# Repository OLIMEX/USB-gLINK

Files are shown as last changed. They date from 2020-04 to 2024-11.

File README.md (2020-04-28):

# USB-gLINK

Industrial grade USB LTE cat 4 module optimized for IoT applications with integrated LiPo Battery power supply charger and Navigation.

Product page: https://www.olimex.com/Products/IoT/LTE/USB-gLINK/open-source-hardware

* Works with OLinuXino OSHW Linux Computers, Beaglebone and Raspberry Pi.

* LTE speed 150Mbps downlink and 50Mbps uplink. Backward-compatible with existing EDGE and GSM/GPRS networks.

* Navigation Supports: GPS, GLONASS, BeiDou/Compass, Galileo and QZSS navigation.

* Protocols: TCP / UDP / PPP / FTP / HTTP / NTP / PING / QMI / NITZ / SMTP / MQTT / CMUX / HTTPS / FTPS / SMTPS / SSL / MMS / FILE.

* USB serial drivers for Windows 7/8/8.1/10, Linux and Android.

* Works anywehere in the world: B1 / B2 / B3 / B4 / B5 / B7 / B8 / B12 / B13 / B18 / B19 / B20 / B25 / B26 / B28 / B38 / B39 / B40 / B41.

* Approvals Carrier: Deutsche Telekom (Europe), Verizon/AT&T/Sprint/U.S. Cellular/T-Mobile (North America), Telus/Rogers (Canada)

* Regulatory: GCF (Global), CE (Europe), FCC/PTCRB (North America), IC (Canada), Anatel (Brazil), IFETEL (Mexico), SRRC/CCC/NAL (China), KC (South Korea), NCC (Taiwan, China), JATE/TELEC (Japan), RCM (Australia & New Zealand), FAC (Russia), NBTC (Thailand), IMDA (Singapore), ICASA (South Africa)

## Licensee
* Hardware is released under CERN Open Hardware Licence Version 2 -
Strongly Reciprocal
* Software is released under GPL3 Licensee
* Documentation is released under CC BY-SA 3.0

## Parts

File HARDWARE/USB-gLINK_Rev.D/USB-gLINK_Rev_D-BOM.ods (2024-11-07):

Qty | Designation | Package | Designator
1 | 0R/R0402 | R_0402_5MIL_DWS | R19
1 | 10R/R0402 | R_0402_5MIL_DWS | R20
5 | 22R/R0402 | R_0402_5MIL_DWS | R13,R14,R16,R17,R18
1 | 100R/R0402 | R_0402_5MIL_DWS | R29
5 | 2.2k/R0402 | R_0402_5MIL_DWS | R6,R7,R8,R9,R10
1 | 4.7k/R0402 | R_0402_5MIL_DWS | R11
1 | 33k/1%/R0603 | R_0603_5MIL_DWS | R3
5 | 10k/R0402 | R_0402_5MIL_DWS | R2,R4,R5,R12,R28
1 | 200k/1%/R0603 | R_0603_5MIL_DWS | R1
1 | 470k/R0402 | R_0402_5MIL_DWS | R30
1 | 1M/R0402 | R_0402_5MIL_DWS | R15
2 | 10pF/50V/5%/COG/C0402 | C_0402_5MIL_DWS | C16,C21
6 | 33pF/50V/5%/COG/C0402 | C_0402_5MIL_DWS | C3,C8,C9,C11,C15,C20
1 | 100pF/50V/5%/COG/C0402 | C_0402_5MIL_DWS | C33
4 | 10nF/10V/10%/X5R/C0402 | C_0402_5MIL_DWS | C10,C30,C31,C32
7 | 100nF/10V/10%/X5R/C0402 | C_0402_5MIL_DWS | C1,C7,C14,C19,C28,C29,C34
5 | 22uF/6.3V/20%/X5R/C0603 | C_0603_5MIL_DWS | C2,C4,C5,C6,C35
4 | 47uF/6.3V/20%/X5R/C0805 | C_0805_5MIL_DWS | C12,C13,C17,C18
1 | 33nH/0402 | L_0402_5MIL_DWS | L2
1 | 2.5uH/3.2A/26mR/20%/10.3x10.4x 3.0mm(HSMRH103R-2R5M) | HSMRH103R | L1
2 | 1N5822/SMA | SMA-KA | D1,D2
1 | 1N5819S4/SOD123 | SOD-123_1C-2A_KA | D3
1 | LED/Green/0603 | LED_0603_KA | ModStat1
2 | LED/Yellow/0603 | LED_0603_KA | CHRG1,NetStat1
1 | LED/Red/0603 | LED_0603_KA | NetMode1
2 | BSS138(SOT23-3) | SOT23 | FET2,FET5
3 | IRLML6402(SOT23-3) | SOT23 | FET1,FET3,FET4
2 | LMUN2211LT1G(SOT23-3) | SOT23 | T2,T3
1 | Quectel_EG25-G_Module | Quectel_EG25-G_Module_LGA- 144_32.0mmx29.0mmx2.4mm | U3
1 | SY8113(SOT23-6) | SOT23-6 | U1
1 | BL4054B-42TPRN(SOT23-5) | SOT-23-5 | U2
1 | SIMNANO-6P-1.3H | SIMNANO-6P-1.3H | SIM1
1 | MISB-SWMM-5B-LF(USB_MICRO) | USB-MICRO_MISB-SWMM-5B_LF | USB-DEV1
1 | DW02S | LIPO_BAT_VERTICAL_DW02S | BAT1
1 | (U.FL-R-SMT-1)+(ANTENNA- GPS-25x25-200-u.FL) | U.FL-R-SMT-1 | ANT_GNSS1
1 | (U.FL-R-SMT-1)+(ANTENNA_ GSM_U.FL(PCB)) | U.FL-R-SMT-1 | ANT_MAIN1
2 | IT1185AU2 | IT1185AU2_V2 | PWR_KEY1,RST_KEY1
1 | Opened | SJ_1_SMALLER | BOOT_E1
1 | Soldered | SJ_1_SMALLER | Start_E1
2 | NA(YA-V36P-2X20-LF) | GPCB127SMT-02X20(YA-V36P-2X20-LF) | EXT2,EXT1
6 | NA/C0402 | C_0402_5MIL_DWS | C22,C23,C24,C25,C26,C27
1 | NA(U.FL-R-SMT-1) | U.FL-R-SMT-1 | ANT_DIV1
1 | NA(0R/R0402) | R_0402_5MIL_DWS | R21
1 | NA(1.5k/R0402) | R_0402_5MIL_DWS | R22
4 | NA(10k/R0402) | R_0402_5MIL_DWS | R23,R24,R25,R32
2 | NA(3.9k/R0402) | R_0402_5MIL_DWS | R26,R27
2 | NA(100nF/10V/10%/X5R/C0402) | C_0402_5MIL_DWS | C36,C37
1 | NA(4.7k/R0402) | R_0402_5MIL_DWS | R31
1 | NA(1M/R0402) | R_0402_5MIL_DWS | R33
1 | NA(470k/R0402) | R_0402_5MIL_DWS | R34

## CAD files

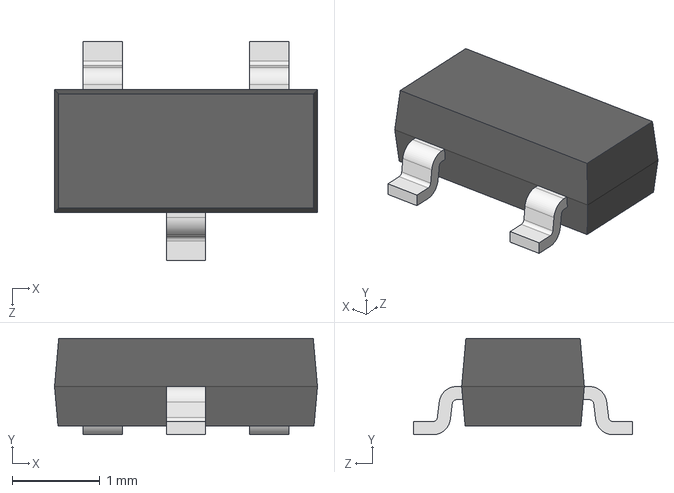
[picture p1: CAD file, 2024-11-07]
HARDWARE/USB-gLINK_Rev.D/3d/SOT-23.step
3.00 x 1.10 x 2.50 mm

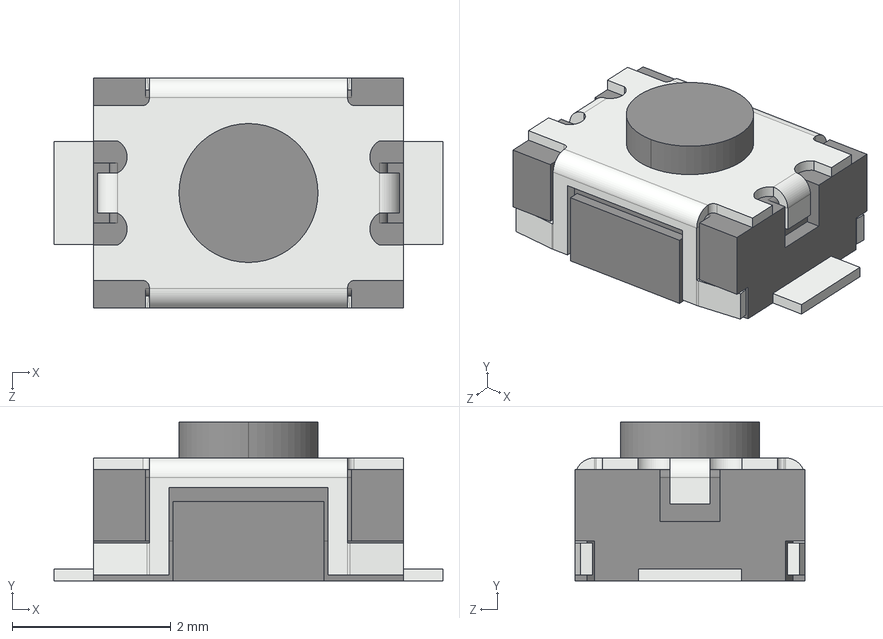
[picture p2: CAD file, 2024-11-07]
HARDWARE/USB-gLINK_Rev.D/3d/it1185.step
4.90 x 2.00 x 2.90 mm

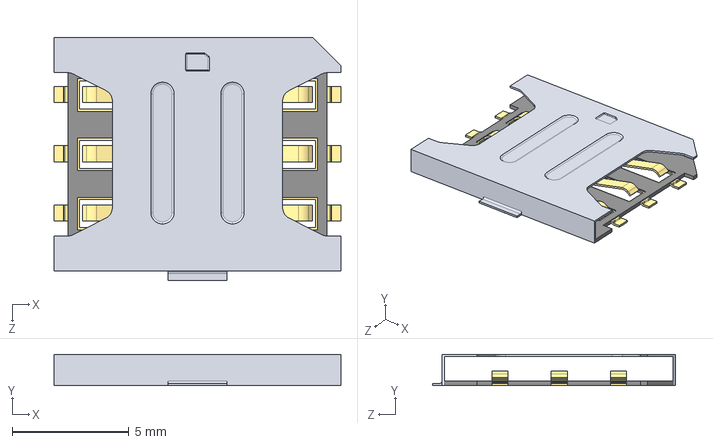
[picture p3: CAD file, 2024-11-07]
HARDWARE/USB-gLINK_Rev.D/3d/User Library-nano sim.STEP
12.3 x 1.35 x 10.4 mm

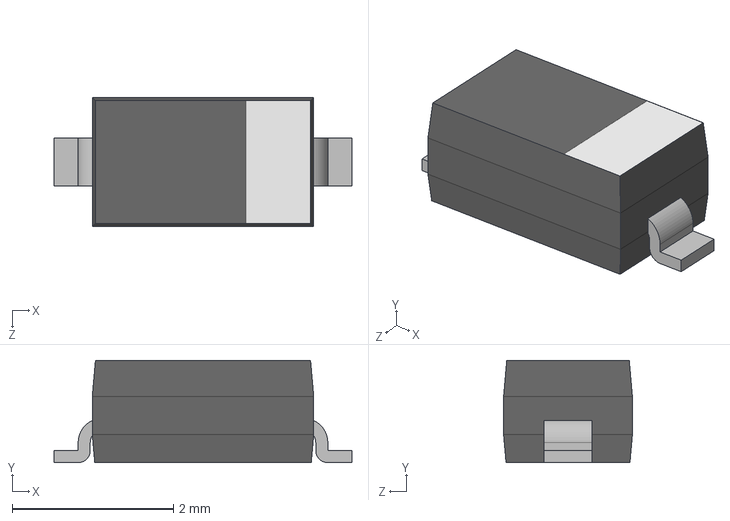
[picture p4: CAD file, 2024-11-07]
HARDWARE/USB-gLINK_Rev.D/3d/SOD123.step
3.70 x 1.27 x 1.60 mm

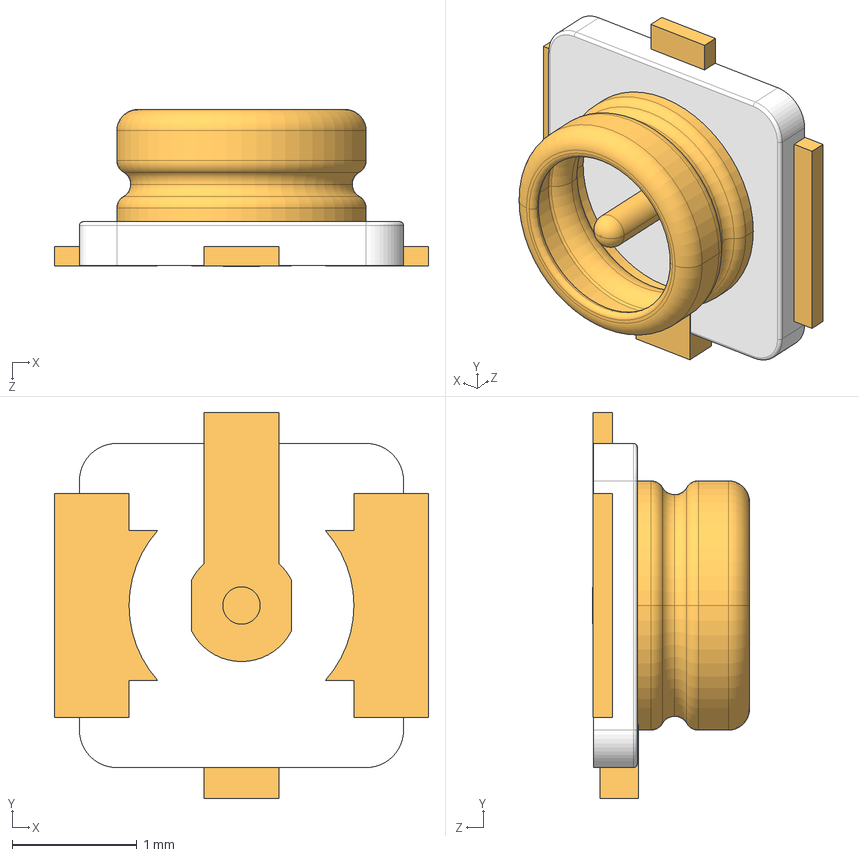
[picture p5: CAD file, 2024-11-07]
HARDWARE/USB-gLINK_Rev.D/3d/U_FL-R-SMT-1.step
3.00 x 3.10 x 1.26 mm

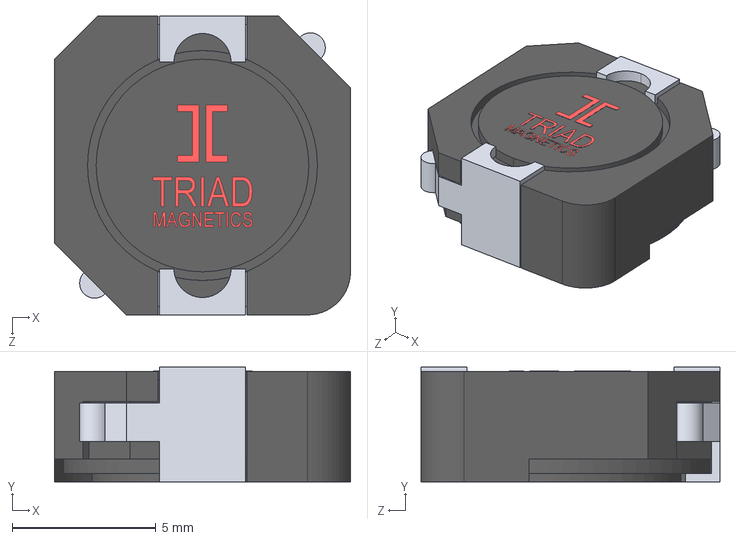
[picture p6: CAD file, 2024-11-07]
HARDWARE/USB-gLINK_Rev.D/3d/L_HSMRH103R_Triad_Magnetics-AX104R-150.STEP
10.3 x 4.00 x 10.4 mm

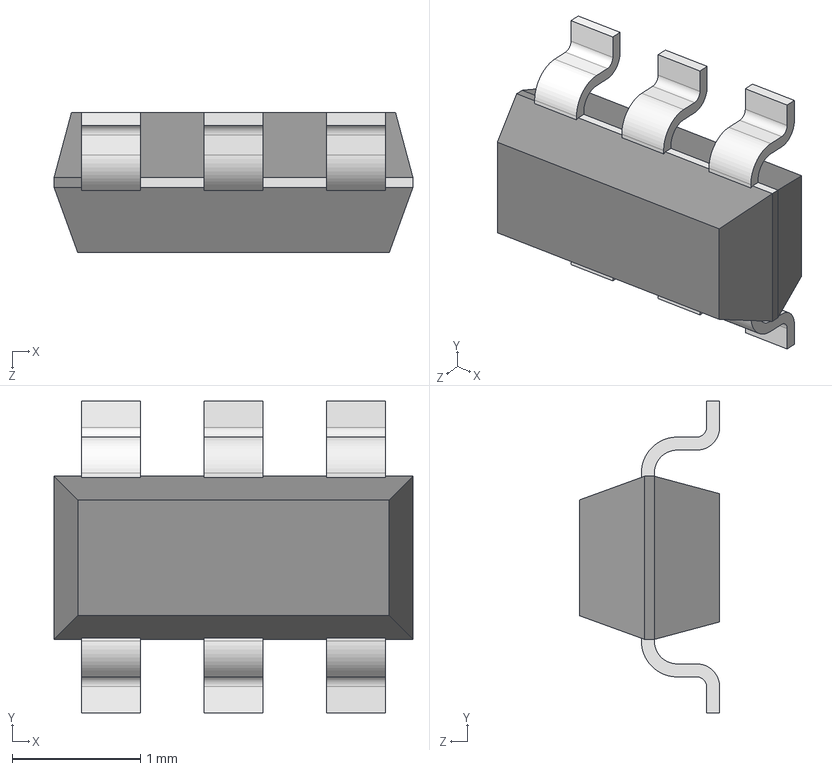
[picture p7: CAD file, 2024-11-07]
HARDWARE/USB-gLINK_Rev.D/3d/SOT-23-6.step
2.79 x 2.43 x 1.09 mm

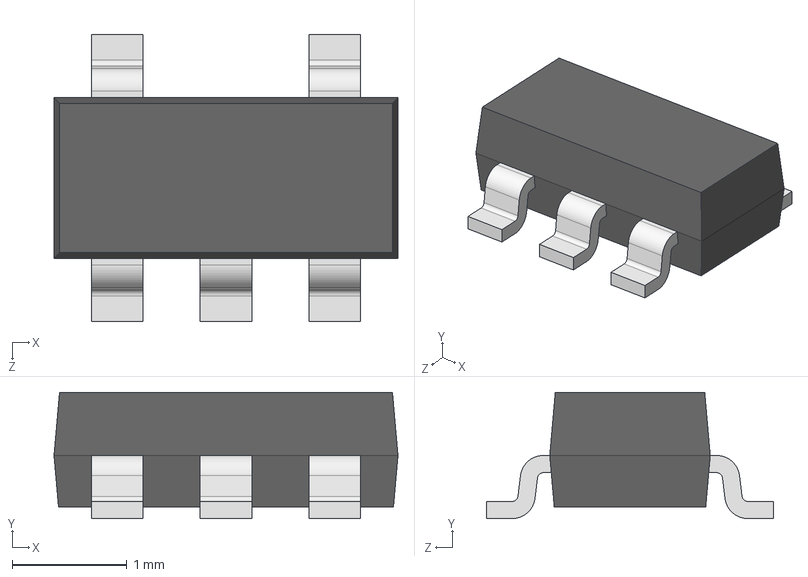
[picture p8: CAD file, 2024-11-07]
HARDWARE/USB-gLINK_Rev.D/3d/SOT-23-5.step
3.00 x 1.10 x 2.50 mm

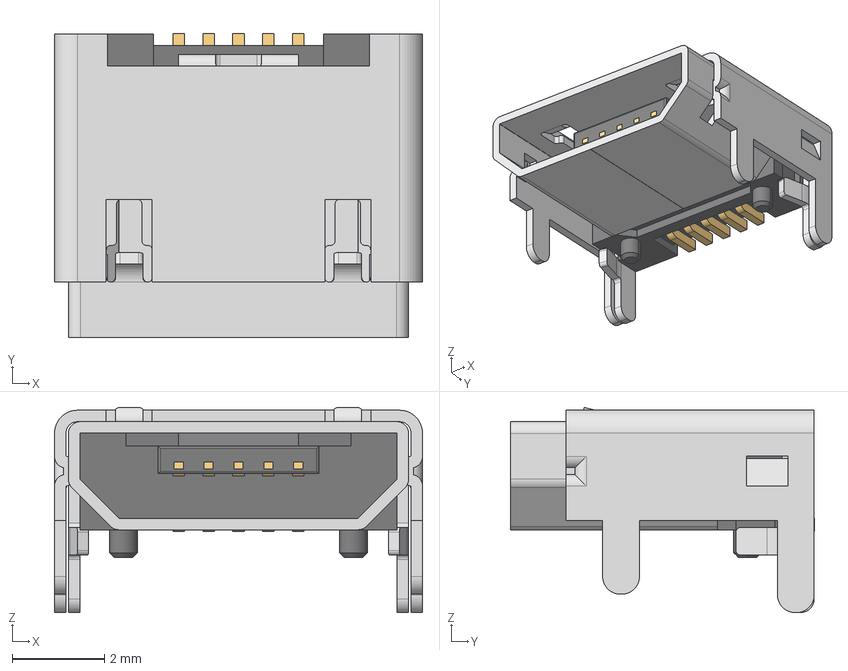
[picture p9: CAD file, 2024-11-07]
HARDWARE/USB-gLINK_Rev.D/3d/usb_micro_4p.stp
8.00 x 6.60 x 4.46 mm

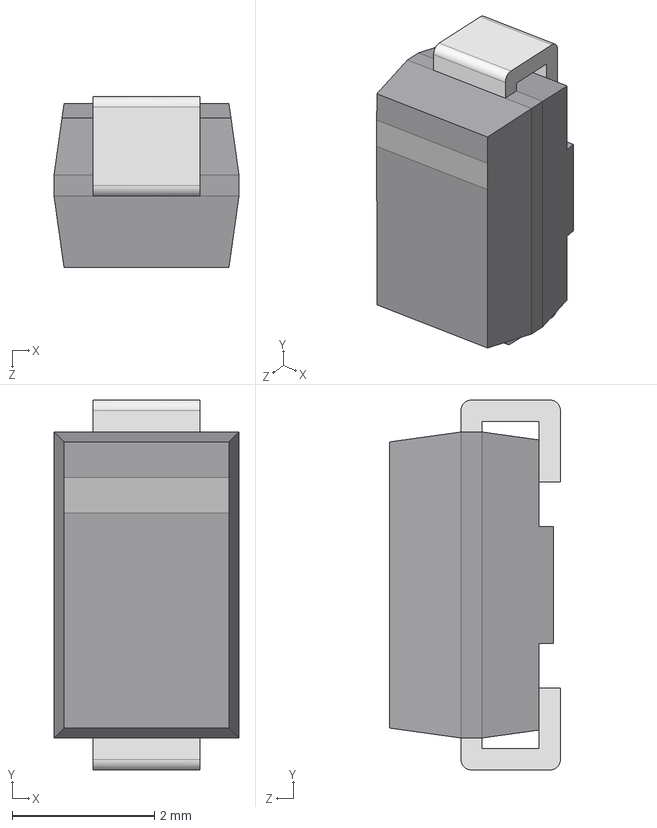
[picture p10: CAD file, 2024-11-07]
HARDWARE/USB-gLINK_Rev.D/3d/DO-214AC_SMA.step
2.60 x 5.20 x 2.40 mm

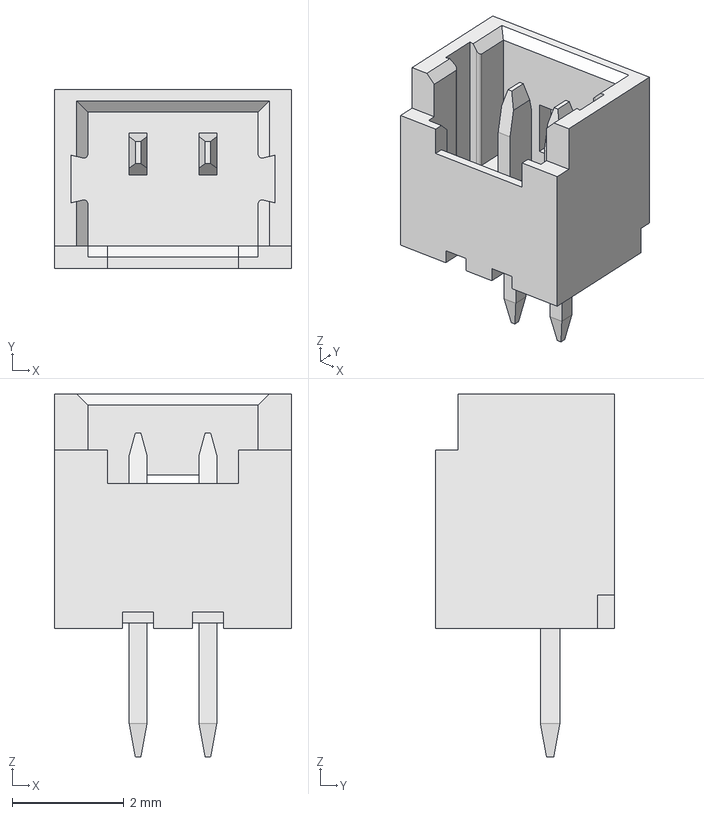
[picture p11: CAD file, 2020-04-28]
HARDWARE/USB-gLINK_Rev.D/3d/Molex_PicoBlade_530470210.step
4.25 x 3.20 x 6.50 mm

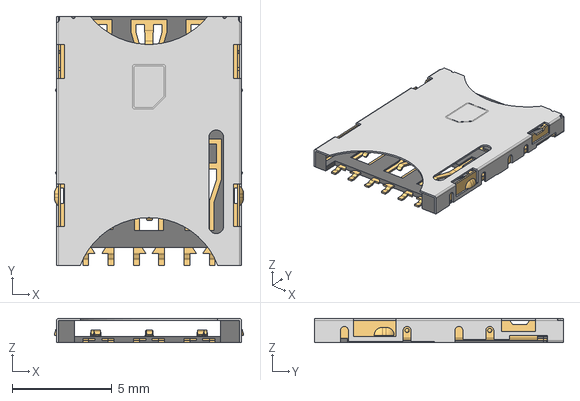
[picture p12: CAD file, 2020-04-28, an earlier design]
HARDWARE/USB-gLINK_Rev.C/3d/NANO-SIM_Wurth_Electronics_693043020611.step
9.50 x 12.5 x 1.21 mm
693043020611_SHIELDING

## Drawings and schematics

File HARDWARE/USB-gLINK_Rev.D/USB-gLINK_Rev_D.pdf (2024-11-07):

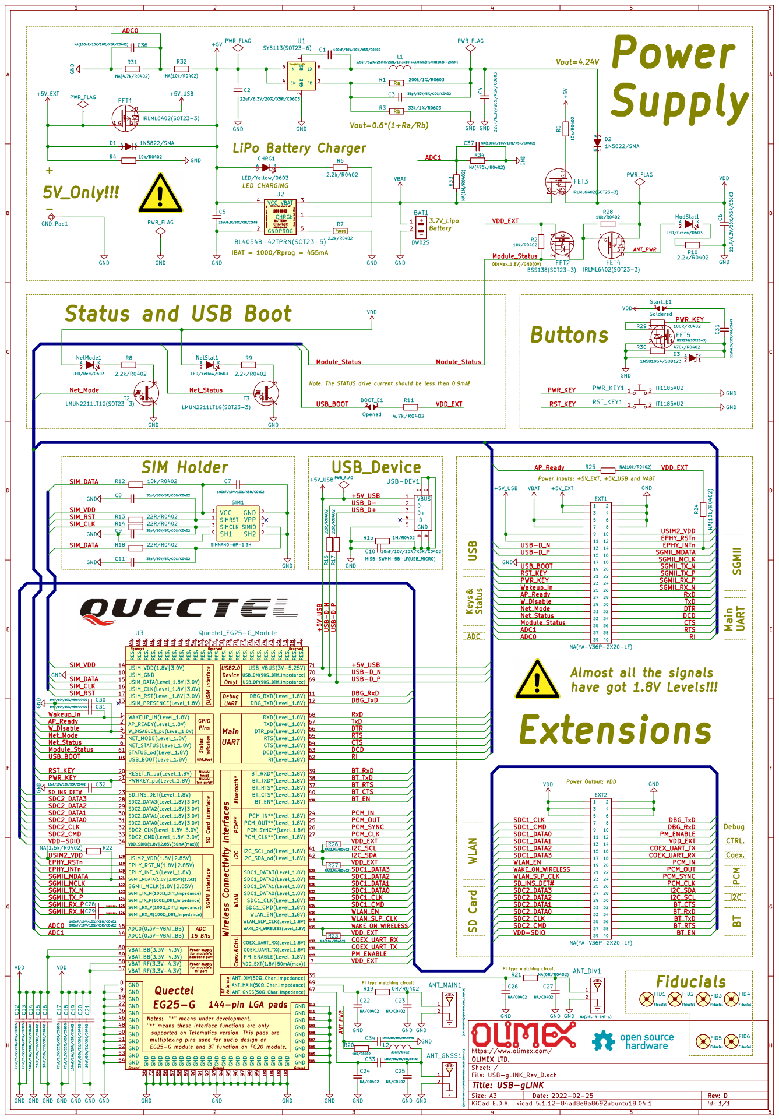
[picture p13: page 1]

3.7V_Lipo Battery Note: The STATUS drive current should be less than 0.9mA!

Power Output: VDD Status and USB Boot

PI type matching circuit SIM Holder

Power Inputs: +5V_EXT, +5V_USB and VABT Almost all the signals
VBAT

PWR_KEY RI DCD
Module Module multiplexing pins used for audio design on Notes:

File: USB-gLINK_Rev_D.sch Sheet: / OLIMEX LTD. https://www.olimex.com/ "*" means under development. "**"means these interface functions are only (U)SIM Interface

for module's GPIO
RF part SD Card Interface SGMII Interface Status

2 ANT_GNSS1 (U.FL-R-SMT-1)+(ANTENNA-GPS-25x25-200-u.FL) 1

Power supply Power supply Quectel

supported on Telematics version. This pads are

EG25-G module and BT function on FC20 module.

Id: 1/1 Title: USB-gLINK

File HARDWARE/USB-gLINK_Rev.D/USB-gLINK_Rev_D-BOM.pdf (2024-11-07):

USB-gLINK_Rev_D_BOM | 02/28/2022

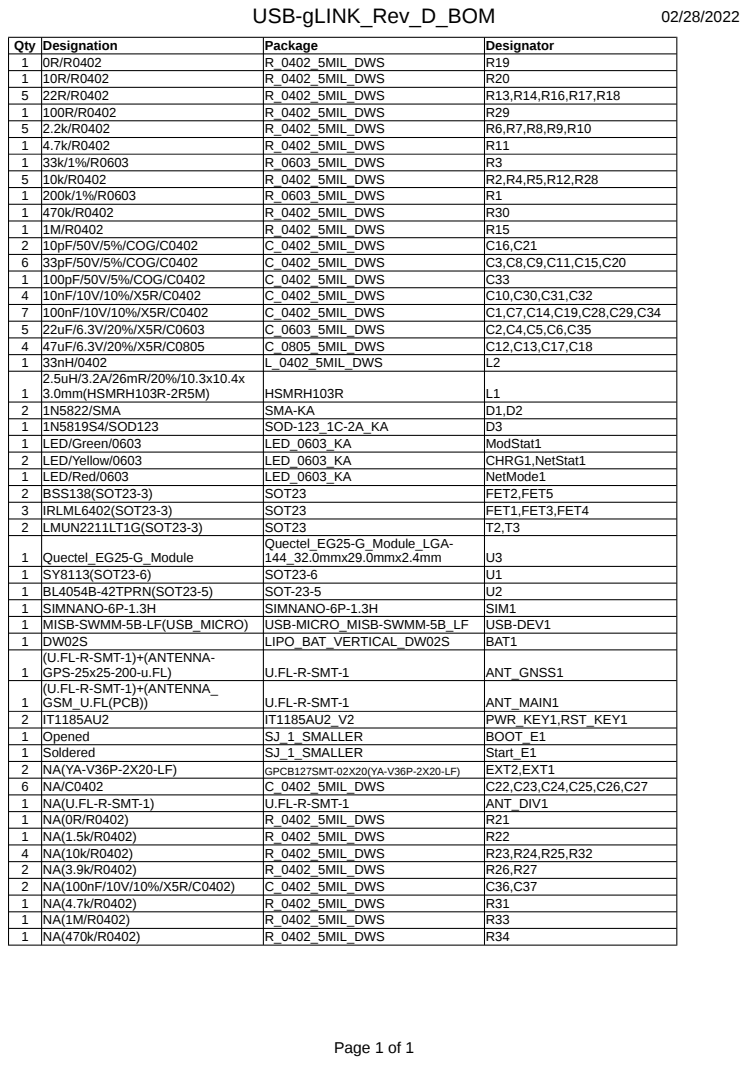
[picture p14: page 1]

1 MISB-SWMM-5B-LF(USB_MICRO) USB-MICRO_MISB-SWMM-5B_LF USB-DEV1
(U.FL-R-SMT-1)+(ANTENNA-
GPS-25x25-200-u.FL)
(U.FL-R-SMT-1)+(ANTENNA_
GSM_U.FL(PCB))

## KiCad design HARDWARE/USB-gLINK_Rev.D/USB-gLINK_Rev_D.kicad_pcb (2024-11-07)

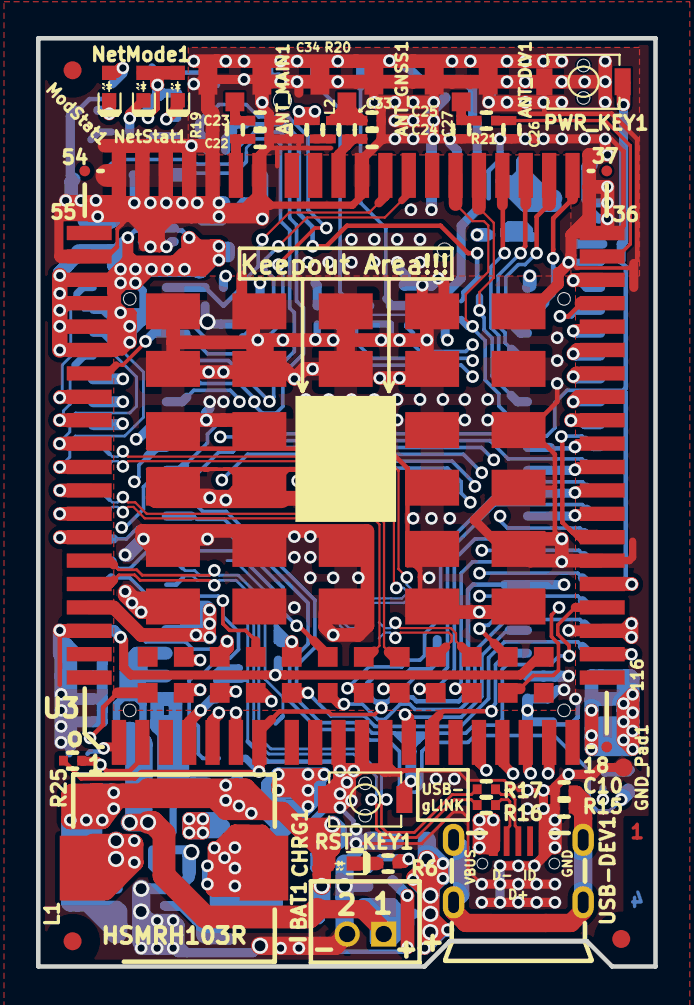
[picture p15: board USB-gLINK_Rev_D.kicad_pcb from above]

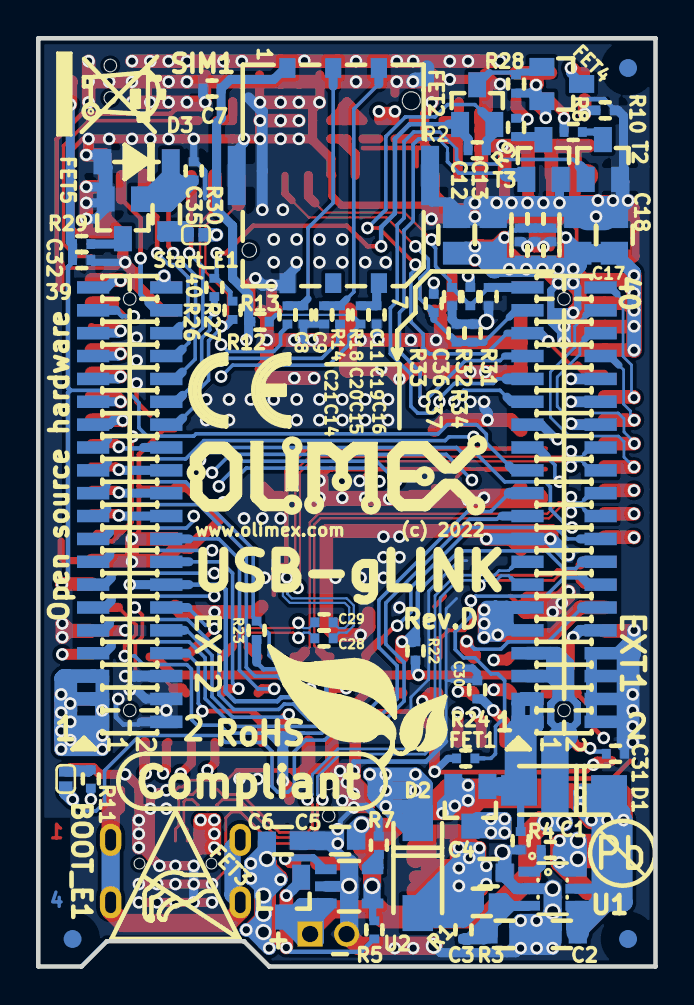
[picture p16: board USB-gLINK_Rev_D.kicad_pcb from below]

Board: 4 copper layers, 34.3 x 51.6 mm, 115 parts (80 on the bottom side), 107 nets.

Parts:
ANT_DIV1: NA(U.FL-R-SMT-1); U.FL-R-SMT-1
ANT_GNSS1: (U.FL-R-SMT-1)+(ANTENNA-GPS-25x25-200-u.FL); U.FL-R-SMT-1
ANT_MAIN1: (U.FL-R-SMT-1)+(ANTENNA_GSM_U.FL(PCB)); U.FL-R-SMT-1
BAT1: DW02S; LIPO_BAT_VERTICAL_DW02S
BOOT_E1: Opened; SJ_1_SMALLER
C1, C7, C14, C19, C28, C29, C34: 100nF/10V/10%/X5R/C0402; C_0402_5MIL_DWS
C2, C4, C5, C6, C35: 22uF/6.3V/20%/X5R/C0603; C_0603_5MIL_DWS
C3, C8, C9, C11, C15, C20: 33pF/50V/5%/COG/C0402; C_0402_5MIL_DWS
C10, C30, C31, C32: 10nF/10V/10%/X5R/C0402; C_0402_5MIL_DWS
C12, C13, C17, C18: 47uF/6.3V/20%/X5R/C0805; C_0805_5MIL_DWS
C16, C21: 10pF/50V/5%/COG/C0402; C_0402_5MIL_DWS
C22, C23, C24, C25, C26, C27: NA/C0402; C_0402_5MIL_DWS
C33: 100pF/50V/5%/COG/C0402; C_0402_5MIL_DWS
C36, C37: NA(100nF/10V/10%/X5R/C0402); C_0402_5MIL_DWS
CE_Logo: CE_Sign
CHRG1: LED/Yellow/0603; LED_0603_KA
D1, D2: 1N5822/SMA; SMA-KA
D3: 1N5819S4/SOD123; SOD-123_1C-2A_KA
EXT1, EXT2: NA(YA-V36P-2X20-LF); GPCB127SMT-02X20(YA-V36P-2X20-LF)
FET1, FET3, FET4: IRLML6402(SOT23-3); SOT23
FET2, FET5: BSS138(SOT23-3); SOT23
FID1, FID2, FID3, FID4, FID5, FID6: Fiducial; Fiducial1x3
GND_Pad1: TESTPAD; TESTPAD_40-ROUND
L1: 2.5uH/3.2A/26mR/20%/10.3x10.4x3.0mm(HSMRH103R-2R5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; HSMRH103R
L2: 33nH/0402; L_0402_5MIL_DWS
Logo_OLimeX: OLIMEX_LOGO_TB
Logo_RecycleBin: LOGO_RECYCLEBIN_1
ModStat1: LED/Green/0603; LED_0603_KA
NetMode1: LED/Red/0603; LED_0603_KA
NetStat1: LED/Yellow/0603; LED_0603_KA
PWR_KEY1: IT1185AU2; IT1185AU2_V2
R1: 200k/1%/R0603; R_0603_5MIL_DWS
R2, R4, R5, R12, R28: 10k/R0402; R_0402_5MIL_DWS
R3: 33k/1%/R0603; R_0603_5MIL_DWS
R6, R7, R8, R9, R10: 2.2k/R0402; R_0402_5MIL_DWS
R11: 4.7k/R0402; R_0402_5MIL_DWS
R13, R14, R16, R17, R18: 22R/R0402; R_0402_5MIL_DWS
R15: 1M/R0402; R_0402_5MIL_DWS
R19: 0R/R0402; R_0402_5MIL_DWS
R20: 10R/R0402; R_0402_5MIL_DWS
R21: NA(0R/R0402); R_0402_5MIL_DWS
R22: NA(1.5k/R0402); R_0402_5MIL_DWS
R23, R24, R25, R32: NA(10k/R0402); R_0402_5MIL_DWS
R26, R27: NA(3.9k/R0402); R_0402_5MIL_DWS
R29: 100R/R0402; R_0402_5MIL_DWS
R30: 470k/R0402; R_0402_5MIL_DWS
R31: NA(4.7k/R0402); R_0402_5MIL_DWS
R33: NA(1M/R0402); R_0402_5MIL_DWS
R34: NA(470k/R0402); R_0402_5MIL_DWS
RST_KEY1: IT1185AU2; IT1185AU2_V2
SIM1: SIMNANO-6P-1.3H
Sign_Antistatic: Val**; LOGO_ANTISTATIC_1
Sign_Pb-Free: LOGO_PBFREE
Sign_RoHS: Val**; LOGO_ROHS_1
Start_E1: Soldered; SJ_1_SMALLER
T2, T3: LMUN2211LT1G(SOT23-3); SOT23
U1: SY8113(SOT23-6); SOT23-6
U2: BL4054B-42TPRN(SOT23-5); SOT-23-5
U3: Quectel_EG25-G_Module; Quectel_EG25-G_Module_LGA-144_32.0mmx29.0mmx2.4mm
USB-DEV1: MISB-SWMM-5B-LF(USB_MICRO); USB-MICRO_MISB-SWMM-5B_LF

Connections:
+5V: C2.1, C5.1, CHRG1.2, D1.1, FET1.2, R5.2, R32.2, U1.4, U1.5, U2.4
+5V_EXT: D1.2, EXT1.1, EXT1.3, FET1.1, R4.2
+5V_USB: EXT1.9, EXT1.11, FET1.3, U3.71, USB-DEV1.1
/ADC0: C36.1, EXT1.39, R31.1, R32.1, U3.45
/ADC1: C37.2, EXT1.37, R33.2, R34.1, U3.44
/ANT_PWR: C34.1, FET4.3, ModStat1.2, R20.2
/AP_Ready: EXT1.27, R25.2, U3.2
/BT_CTS: EXT2.32, U3.40
/BT_EN: EXT2.40, U3.139
/BT_RTS: EXT2.38, U3.37
/BT_RxD: EXT2.34, U3.39
/BT_TxD: EXT2.36, U3.38
/COEX_UART_RX: EXT2.18, U3.137
/COEX_UART_TX: EXT2.16, U3.138
/CTS: EXT1.36, U3.64
/DBG_RxD: EXT2.10, U3.11
/DBG_TxD: EXT2.8, U3.12
/DCD: EXT1.34, U3.63
/DTR: EXT1.32, U3.66
/EPHY_INTn: EXT1.14, R24.1, U3.120
/EPHY_RSTn: EXT1.12, U3.119
/I2C_SCL: EXT2.30, R26.2, U3.41
/I2C_SDA: EXT2.28, R27.2, U3.42
/Module_Status: EXT1.35, FET2.2, R2.1, U3.61
/Net_Mode: EXT1.31, T2.1, U3.5
/Net_Status: EXT1.33, T3.1, U3.6
/PCM_CLK: EXT2.26, U3.27
/PCM_IN: EXT2.20, U3.24
/PCM_OUT: EXT2.22, U3.25
/PCM_SYNC: EXT2.24, U3.26
/PM_ENABLE: EXT2.12, U3.127
/PWR_KEY: C32.1, EXT1.23, PWR_KEY1.1, R29.2, U3.21
/RI: EXT1.40, U3.62
/RST_KEY: EXT1.21, RST_KEY1.1, U3.20
/RTS: EXT1.38, U3.65
/RxD: EXT1.28, U3.68
/SDC1_CLK: EXT2.7, U3.133
/SDC1_CMD: EXT2.9, U3.134
/SDC1_DATA0: EXT2.11, U3.132
/SDC1_DATA1: EXT2.13, U3.131
/SDC1_DATA2: EXT2.15, U3.130
/SDC1_DATA3: EXT2.17, U3.129
/SDC2_CLK: EXT2.35, U3.32
/SDC2_CMD: EXT2.37, U3.33
/SDC2_DATA0: EXT2.33, U3.31
/SDC2_DATA1: EXT2.31, U3.30
/SDC2_DATA2: EXT2.29, U3.29
/SDC2_DATA3: EXT2.27, U3.28
/SD_INS_DET#: EXT2.25, U3.23
/SGMII_MCLK: EXT1.18, U3.122
/SGMII_MDATA: EXT1.16, R22.1, U3.121
/SGMII_RX+: C28.2, U3.125
/SGMII_RX-: C29.2, U3.126
/SGMII_RX_N: C29.1, EXT1.26
/SGMII_RX_P: C28.1, EXT1.24
/SGMII_TX_N: EXT1.20, U3.123
/SGMII_TX_P: EXT1.22, U3.124
/SIM_CLK: R14.1, U3.16
/SIM_DATA: R12.1, R18.1, U3.15
/SIM_RST: R13.1, U3.17
/SIM_VDD: C7.2, R12.2, SIM1.1, U3.14
/TxD: EXT1.30, U3.67
/USB-D_N: EXT1.13, R16.1, U3.70
/USB-D_P: EXT1.15, R17.1, U3.69
/USB_BOOT: BOOT_E1.2, EXT1.19, U3.115
/USB_D+: R17.2, USB-DEV1.3
/USB_D-: R16.2, USB-DEV1.2
/USIM2_VDD: EXT1.10, R22.2, U3.128
/VDD-SDIO: EXT2.39, U3.34
/VDD_EXT: EXT2.14, FET2.1, R2.2, R11.1, R23.1, R24.2, R25.1, R26.1, R27.1, U3.7
/WAKE_ON_WIRELESS: EXT2.21, R23.2, U3.135
/WLAN_EN: EXT2.19, U3.136
/WLAN_SLP_CLK: EXT2.23, U3.118
/W_Disable: C30.1, EXT1.29, U3.4
/Wakeup_In: C31.1, EXT1.25, U3.1
GND: ANT_DIV1.2, ANT_GNSS1.2, ANT_MAIN1.2, BAT1.2, C2.2, C4.2, C5.2, C6.2, C7.1, C8.2, C9.2, C10.2, C11.2, C12.2, C13.2, C14.2, C15.2, C16.2, C17.2, C18.2, C19.2, C20.2, C21.2, C22.1, C23.1, C24.1, C25.1, C26.1, C27.1, C30.2, C31.2, C32.2, C34.2, C36.2, C37.1, D3.2, EXT1.2, EXT1.4, EXT1.6, EXT1.8, EXT1.17, EXT2.2, EXT2.4, EXT2.6, FET5.2, GND_Pad1.1, PWR_KEY1.2, R3.2, R4.1, R7.2, R10.2, R15.2, R30.1, R31.2, R34.2, RST_KEY1.2, SIM1.0, SIM1.5, T2.2, T3.2, U1.2, U2.2, U3.8, U3.9, U3.10, U3.19, U3.22, U3.36, U3.46, U3.48, U3.50, U3.51, U3.52, U3.53, U3.54, U3.56, U3.72, U3.85, U3.86, U3.87, U3.88, U3.89, U3.90, U3.91, U3.92, U3.93, U3.94, U3.95, U3.96, U3.97, U3.98, U3.99, U3.100, U3.101, U3.102, U3.103, U3.104, U3.105, U3.106, U3.107, U3.108, U3.109, U3.110, U3.111, U3.112, USB-DEV1.5
unnamed: ANT_DIV1.1, C27.2, R21.1
unnamed: ANT_GNSS1.1, C25.2, C33.2, L2.2
unnamed: ANT_MAIN1.1, C23.2, R19.1
unnamed: BOOT_E1.1, R11.2
unnamed: C1.1, U1.1
unnamed: C1.2, L1.1, U1.6
unnamed: C3.1, R1.1, R3.1, U1.3
unnamed: C3.2, C4.1, D2.2, L1.2, R1.2
unnamed: C8.1, R13.2, SIM1.2
unnamed: C9.1, R14.2, SIM1.3
unnamed: C10.1, R15.1, USB-DEV1.0
unnamed: C11.1, R18.2, SIM1.7
unnamed: C22.2, R19.2, U3.49
unnamed: C24.2, C33.1, U3.47
unnamed: C26.2, R21.2, U3.35
unnamed: C35.1, Start_E1.2
unnamed: C35.2, D3.1, FET5.1, R30.2
unnamed: CHRG1.1, R6.1
unnamed: FET2.3, FET4.1, R28.2
unnamed: FET3.1, R5.1
unnamed: FET5.3, R29.1
unnamed: L2.1, R20.1
unnamed: ModStat1.1, R10.1
unnamed: NetMode1.1, R8.1
unnamed: NetStat1.1, R9.1
unnamed: R6.2, U2.1
unnamed: R7.1, U2.5
unnamed: R8.2, T2.3
unnamed: R9.2, T3.3
VBAT: BAT1.1, EXT1.5, EXT1.7, FET3.3, R33.1, U2.3
VDD: C6.1, C12.1, C13.1, C14.1, C15.1, C16.1, C17.1, C18.1, C19.1, C20.1, C21.1, D2.1, EXT2.1, EXT2.3, EXT2.5, FET3.2, FET4.2, NetMode1.2, NetStat1.2, R28.1, Start_E1.1, U3.57, U3.58, U3.59, U3.60

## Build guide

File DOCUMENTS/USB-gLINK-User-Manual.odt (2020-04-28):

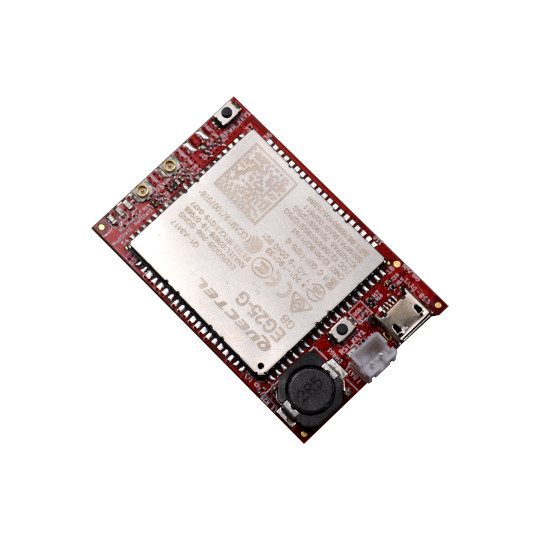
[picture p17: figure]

USB-gLINK

User Manual

Rev.1.0 April 2020

olimex.com

# What is USB-gLINK

USB-gLINK is Open Source Hardware Industrial grade -25+85ºC LTE cat 4 module optimized for IoT applications with integrated LiPo Battery power supply charger and Navigation.

USB-gLINK will work with OLinuXino OSHW Linux Computers, Beaglebone and Raspberry Pi and any other PC running Windows, Linux or Android.

The LTE speed is 150Mbps downlink and 50Mbps uplink, but is backward-compatible with existing EDGE and GSM/GPRS networks. This allows USB-gLINK to connect to any existing 2G, 3G and 4G network.

Inside USB-gLINK there is build in navigation which supports: GPS, GLONASS, BeiDou/Compass, Galileo and QZSS.

The networking supported protocols are : TCP / UDP / PPP / FTP / HTTP / NTP / PING / QMI / NITZ / SMTP / MQTT / CMUX / HTTPS / FTPS / SMTPS / SSL / MMS / FILE.

USB-gLINK can operate on these bands: B1 / B2 / B3 / B4 / B5 / B7 / B8 / B12 / B13 / B18 / B19 / B20 / B25 / B26 / B28 / B38 / B39 / B40 / B41, which covers every mobile operator anywhere in the world. This allow your solution based on USB-gLINK to be sold globally without hardware changes.

There are number of carriers who already approved the module used in USB-gLINK: Deutsche Telekom (Europe), Verizon/AT&T/Sprint/U.S. Cellular/T-Mobile (North America), Telus/Rogers (Canada)

These regulatory are passed: GCF (Global), CE (Europe), FCC/PTCRB (North America), IC (Canada), Anatel (Brazil), IFETEL (Mexico), SRRC/CCC/NAL (China), KC (South Korea), NCC (Taiwan, China), JATE/TELEC (Japan), RCM (Australia & New Zealand), FAC (Russia), NBTC (Thailand), IMDA (Singapore), ICASA (South Africa)

# USB-gLINK ordering options

USB-gLINK can be ordered as:

- USB-gLINK (https://www.olimex.com/Products/IoT/LTE/USB-gLINK/open-source-hardware) just the module
- USB-gLINK-ANT (https://www.olimex.com/Products/IoT/LTE/USB-gLINK-ANT/open-source-hardware) the module with GSM multiband antenna and GPS active antenna
- we also recommend you to buy USB (https://www.olimex.com/Products/Components/Cables/USB-CABLE-A-MICRO-1.8M/)micro (https://www.olimex.com/Products/Components/Cables/USB-CABLE-A-MICRO-1.8M/) cable (https://www.olimex.com/Products/Components/Cables/USB-CABLE-A-MICRO-1.8M/) if you do not have
- we offer LiPo batteries (https://www.olimex.com/Products/Power/BATTERY-LIPO1400mAh/) compatible with USB-gLINK but as these batteries are subject to many transport regulations they can be shipped only by ground i.e. in EU countries

# USB-gLINK Open Source Licensee

USB-gLINK is Open Source Hardware.

The Hardware files are released under CERN OSHW licensee (https://github.com/OLIMEX/USB-gLINK/blob/master/cern_ohl_s_v2.pdf).

The software is released under GPL 3 licensee (https://github.com/OLIMEX/USB-gLINK/blob/master/LICENSE).

The documentation is released under CC BY-SA 3.0 (https://creativecommons.org/licenses/by-sa/3.0/) licensee.

# USB-gLINK software installation

If you use OLinuXino Linux SBC computers you can use the install script from this package (https://github.com/OLIMEX/USB-gLINK/blob/master/SOFTWARE/LINUIX-ARM/USB-GLINK_WDM.zip).

Note that before you run the scrip you have to change settings.ini and to fill inside it user/pin/gateway information.

For Windows PC use these drivers (https://github.com/OLIMEX/USB-gLINK/tree/master/SOFTWARE/WINDOWSx86).

For Linux PC (x86) use these drivers (https://github.com/OLIMEX/USB-gLINK/tree/master/SOFTWARE/LINUXx86).

For Android use these drivers (https://github.com/OLIMEX/USB-gLINK/tree/master/SOFTWARE/ANDROID).

# USB-gLINK connectors description:

YELLOW LED:

Flicker slowly (200ms High/1800ms Low) - search network

Flicker slowly (1800ms High/200ms Low) – Idle

Flicker quickly (125ms High/125ms Low) – data transfer

ON – voice call

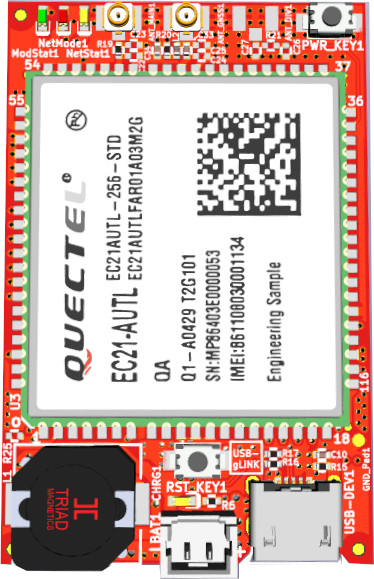
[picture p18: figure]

RESET button

USB connector

LiPo battery connector

LiPo charge LED

PWR button

GPS antenna

GSM antenna

RED LED: On – registered to LTE network

GREEN LED: Module status – ON module is working

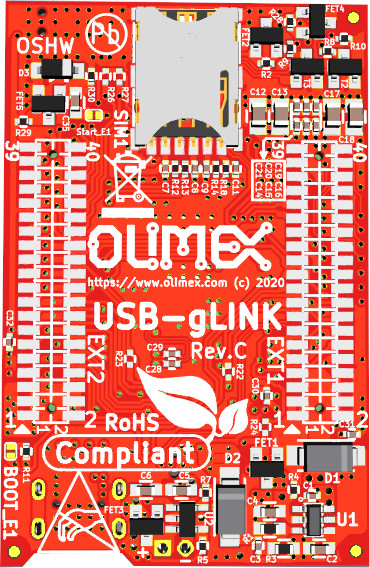
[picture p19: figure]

NANO SIM

EXT1

EXT2

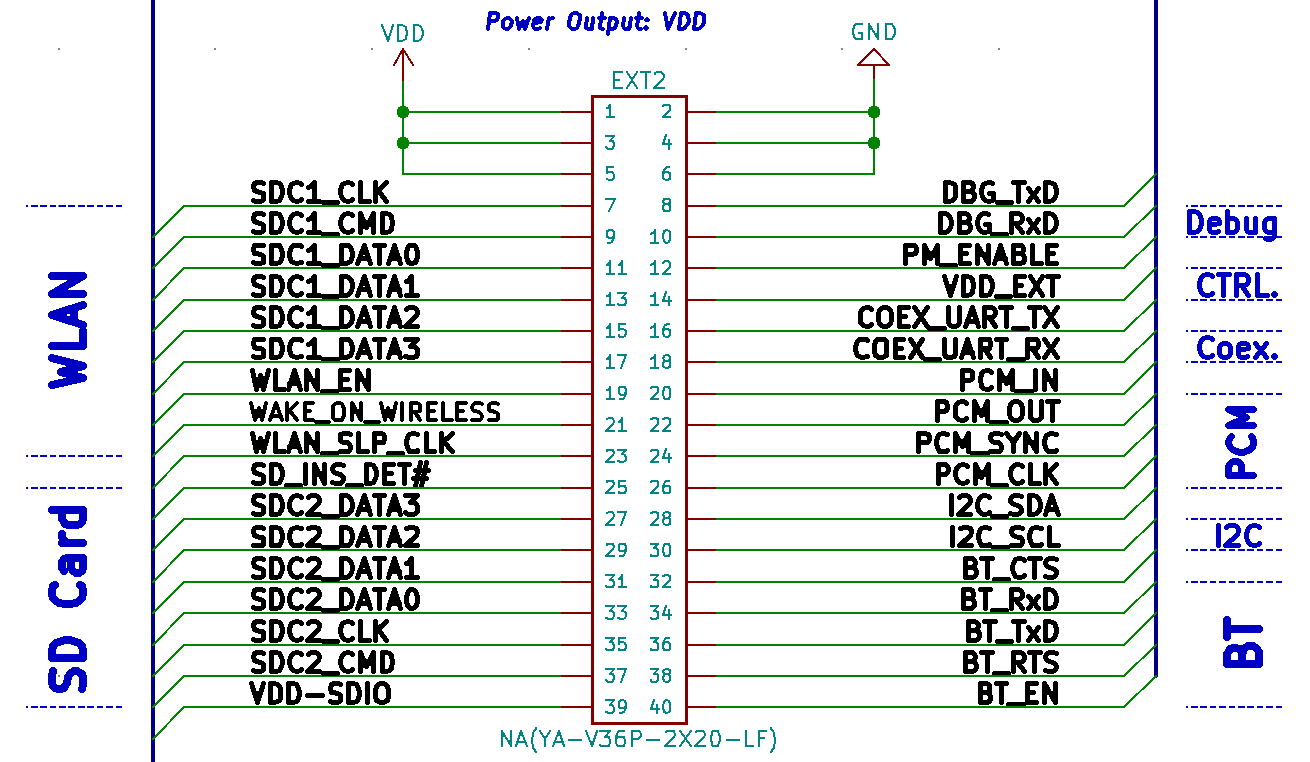
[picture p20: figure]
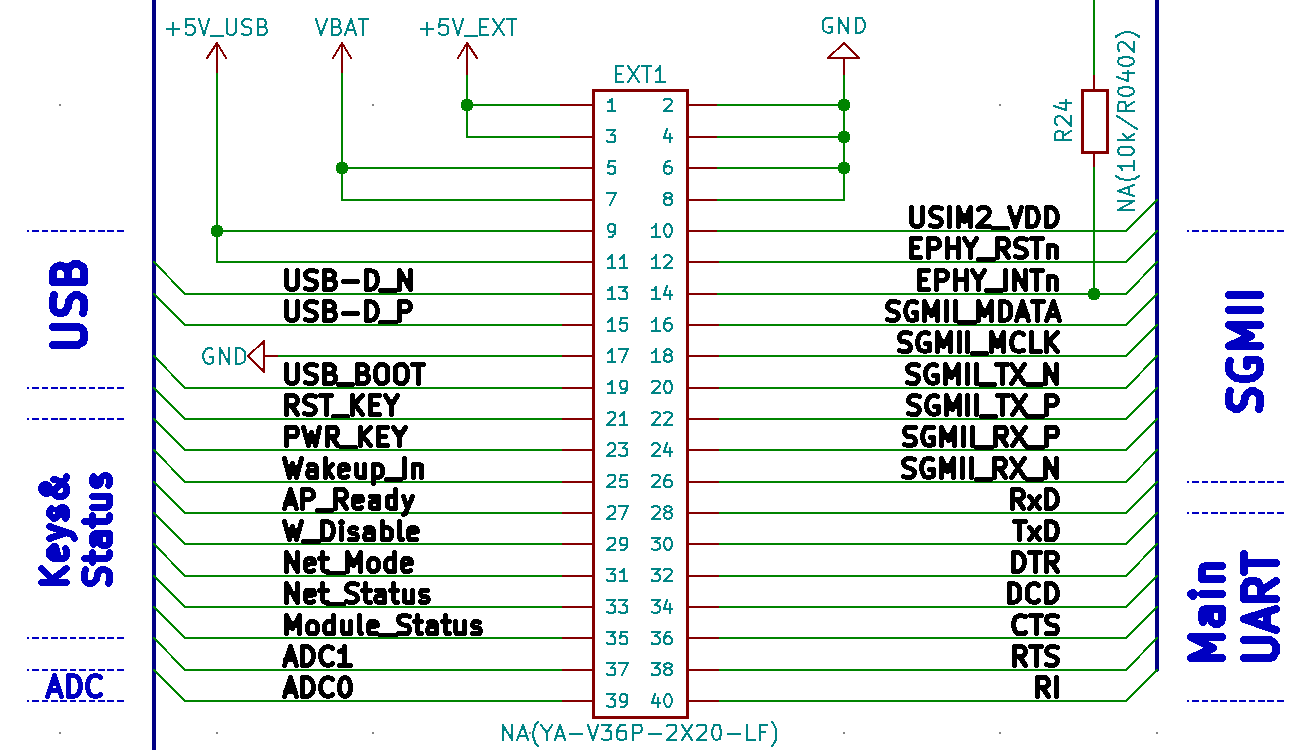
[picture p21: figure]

# USB-gLINK power consumption

- 0.2A @ Active operation
- 22mA @ Idle
- 3mA @ Sleep
- 20 uA @ Power off

# Revision History

Revision 1.0 April 2020

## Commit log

2020-04-28 initial upload CAD and docs
    [DO-214AC_SMA.step, L_HSMRH103R_Triad_Magnetics-AX104R-150.STEP, Molex_PicoBlade_530470210.step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]
2024-11-07 Update
    Hardware revision D
    [DO-214AC_SMA.step, L_HSMRH103R_Triad_Magnetics-AX104R-150.STEP, Molex_PicoBlade_530470210.step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]
2024-11-07 Update
    Latest hardware revision
    [USB-gLINK_Rev_D.kicad_pcb, USB-gLINK_Rev_D.sch]

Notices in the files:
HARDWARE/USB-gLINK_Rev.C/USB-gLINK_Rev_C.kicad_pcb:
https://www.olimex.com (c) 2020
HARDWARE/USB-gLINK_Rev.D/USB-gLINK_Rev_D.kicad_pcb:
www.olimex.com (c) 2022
